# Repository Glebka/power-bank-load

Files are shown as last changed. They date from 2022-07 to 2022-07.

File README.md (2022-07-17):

# PowerBankLoad

This device prevents my power bank from sleep when I am trying to power my DIY devices that draw less than 150 mA of power.

It is inspired by the blog post [Battery Pack Load](https://dorkbotpdx.org/blog/paul/battery_pack_load/) by Paul.

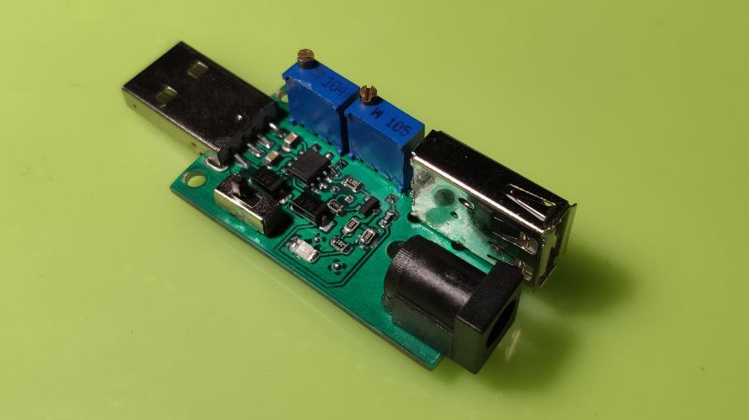
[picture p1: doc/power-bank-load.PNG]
PowerBankLoad device


I changed a schematic, so it uses 555 timer to generate pulses instead of two bipolar transistors.
Well,  you may say that it is an overkill, however, I feel more comfortable with timer than with two transistors I need to adjust.
As a bonus, device supports adjusting pulse width and frequency.

## 3D View

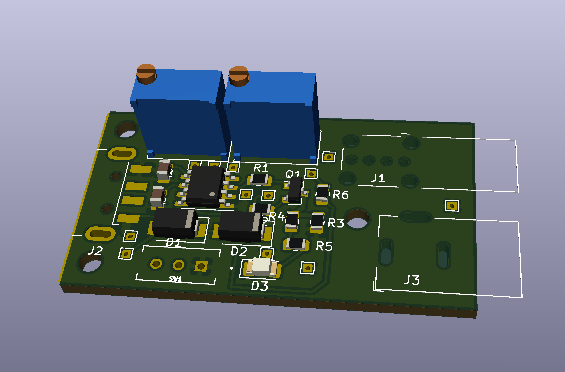
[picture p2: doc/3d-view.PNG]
PCB in 3D


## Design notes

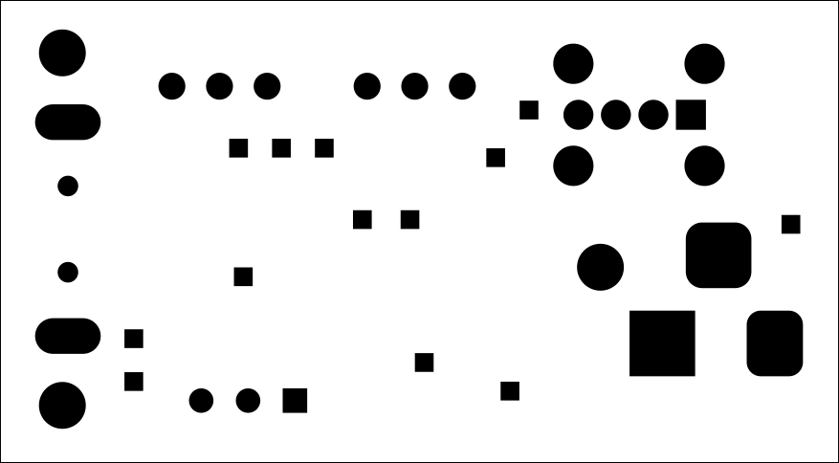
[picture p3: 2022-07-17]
cad/electronics/svg/b-mask.png

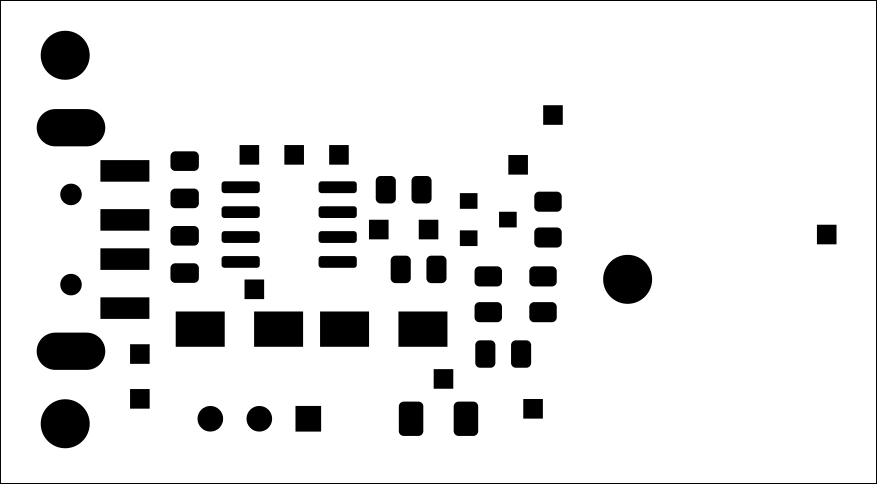
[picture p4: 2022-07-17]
cad/electronics/svg/f-mask.png

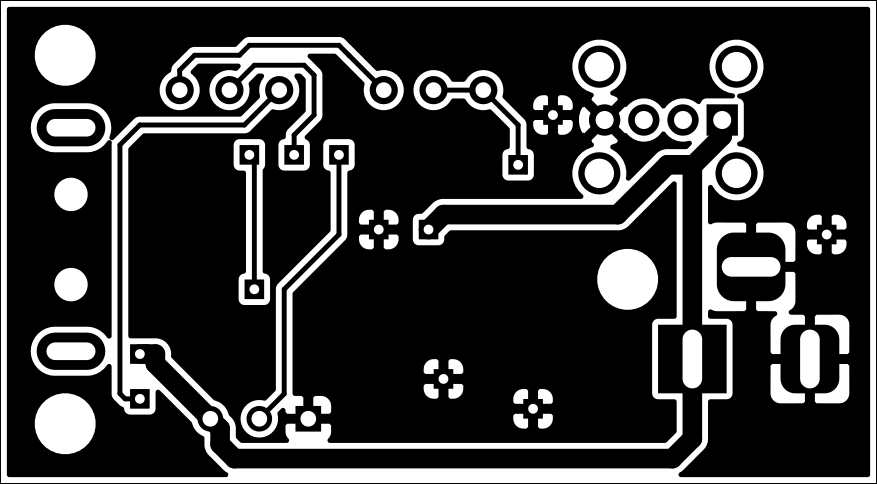
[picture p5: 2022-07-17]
cad/electronics/svg/b-cu.png

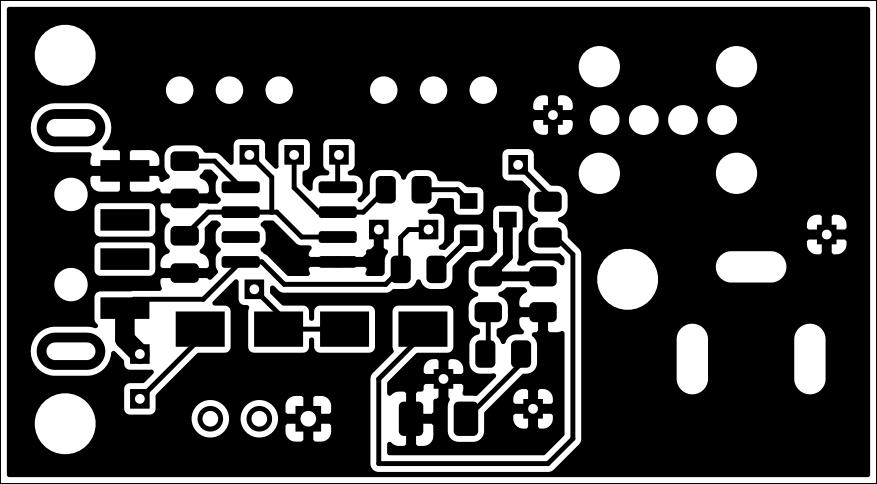
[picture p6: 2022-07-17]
cad/electronics/svg/f-cu.png

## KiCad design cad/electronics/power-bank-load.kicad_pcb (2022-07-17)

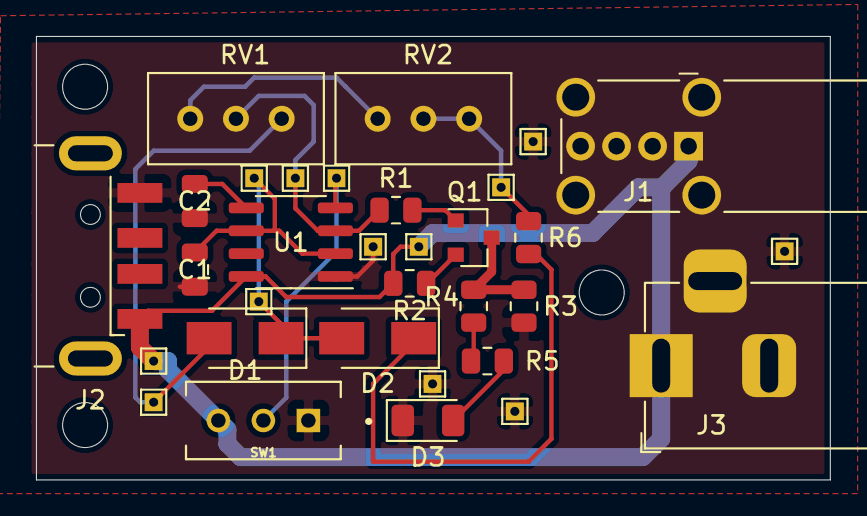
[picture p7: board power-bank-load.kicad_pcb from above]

Board: 2 copper layers, 44.1 x 24.6 mm, 19 parts (0 on the bottom side), 15 nets.

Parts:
C1, C2: 1uF; C_0805_2012Metric
D1, D2: 1N401; D_SMA
D3: LED; LED_1206_3216Metric
J1: USB_A; USB_A_Wuerth_614004134726_Horizontal
J2: USB_A; USB_A_CNCTech_1001-011-01101_Horizontal
J3: Barrel_Jack_Switch; BarrelJack_Horizontal
Q1: MMBT2222A; SOT-23
R1, R5: 1k; R_0805_2012Metric
R2: 22; R_0805_2012Metric
R3, R4: 0; R_0805_2012Metric
R6: 680k; R_0805_2012Metric
RV1: 100k; Potentiometer_Bourns_3296W_Vertical
RV2: 1M; Potentiometer_Bourns_3296W_Vertical
SW1: SW_SPDT; SW_OS102011MS2QN1
U1: NE555D; SOIC-8_3.9x4.9mm_P1.27mm

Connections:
+5V: J1.1, J2.1, J3.1, R2.1, SW1.3, U1.8
GND: C1.2, C2.2, D3.1, J1.4, J2.4, J3.2, J3.3, R3.2, SW1.1, U1.1
unnamed: C1.1, D1.1, D2.2, U1.2, U1.6
unnamed: C2.1, U1.5
unnamed: D1.2, RV1.3
unnamed: D2.1, R6.1
unnamed: D3.2, R5.2
unnamed: Q1.1, R1.1
unnamed: Q1.2, R2.2
unnamed: Q1.3, R3.1, R4.1
unnamed: R1.2, RV1.2, U1.3
unnamed: R4.2, R5.1
unnamed: R6.2, RV2.2, RV2.3
unnamed: RV1.1, RV2.1
unnamed: SW1.2, U1.4
